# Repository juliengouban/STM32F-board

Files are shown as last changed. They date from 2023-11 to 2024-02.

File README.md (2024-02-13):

# Project PCB STM32F board



The PCB board is based on an STM32F microcontroller. It's similar to the ST Microelectronics Nucleo, which also features an STM32F. 

The board was realized on Altium Designer. It was produced by prototypist PCBway. This is a 4-layer PCB (top layer, GND layer, 3.3v layer and bottom layer) using vias.

*Project duration: 3 days*

# Table of contents
- [Electronic diagram](#electronic-diagram)
- [PCB Design](#pcb-design)

## Electronic diagram

The board's circuit diagram includes a two-pin male connector for the external power supply. This allows the board to be powered from 4 to 20 volts. A voltage regulator is used to convert the input voltage to 3.3V.

The middle of the page shows the STM32F microcontroller. It has 43 pins, 30 of which are GPIOS controllable. This board use an external quartz oscillator to provide a stable frequency for this board.
The Reset pin on the microcontroller is connected to a pushbutton to reset the STM32F board.The STM32F has different boot options. The user is given the choice with a male connector.
The STM32F board has a JTAG (Joint Test Action Group) interface for testing, debugging and programming this board.
The board has two female connectors for connecting components to the board's GPIO. There are 30 GPIOS usable on the STM32F board.

Each GPIO has a pull-up resistor.
The bypass capacitor (decoupling capacitor) is used on our board to stabilize the power supply to the components.

Its main role is to filter and eliminate the high-frequency electrical noise generated by these components.

For routing placement, the bypass capacitor is connected between the supply line and ground (GND) in the immediate vicinity of the component it supplies. 
Here is the complete circuit diagram:

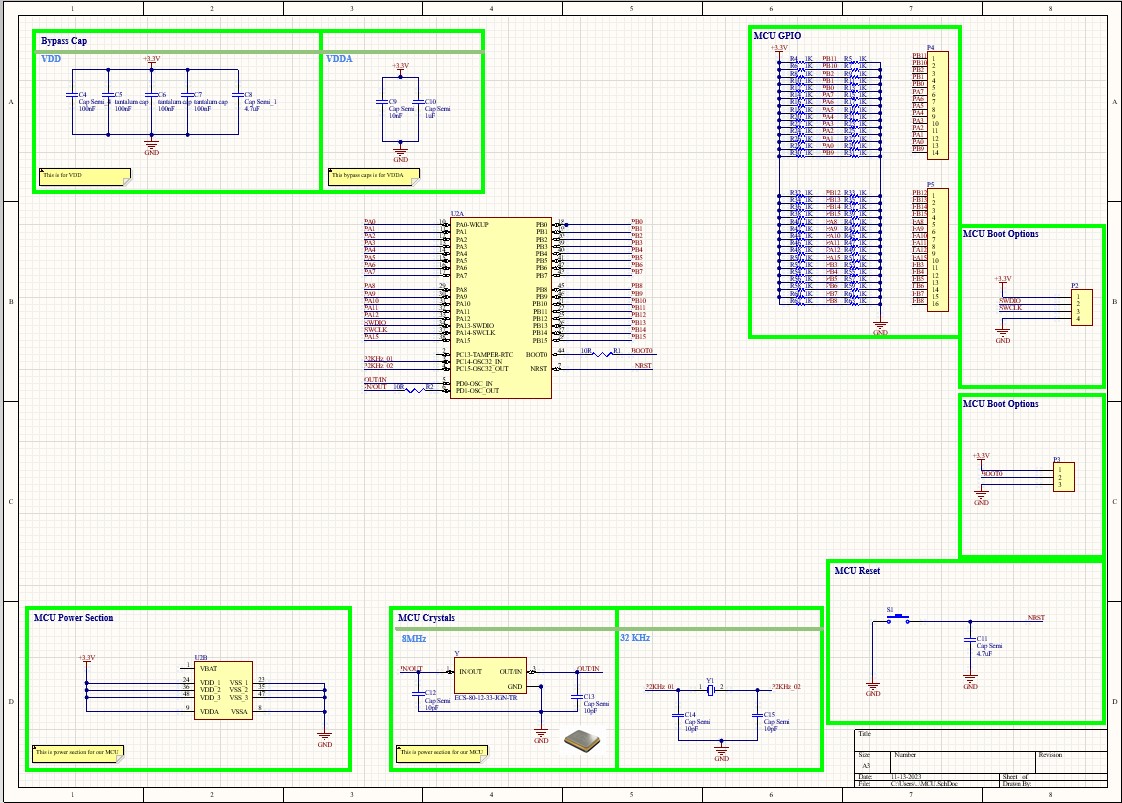
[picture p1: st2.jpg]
 

## PCB Design

The PCB has been realized on Altium Designer. It has a dimension of 6.5 cm and a height of 5 cm.  The board's top layer contains most of the components. 

Here's the top layer view of the PCB:

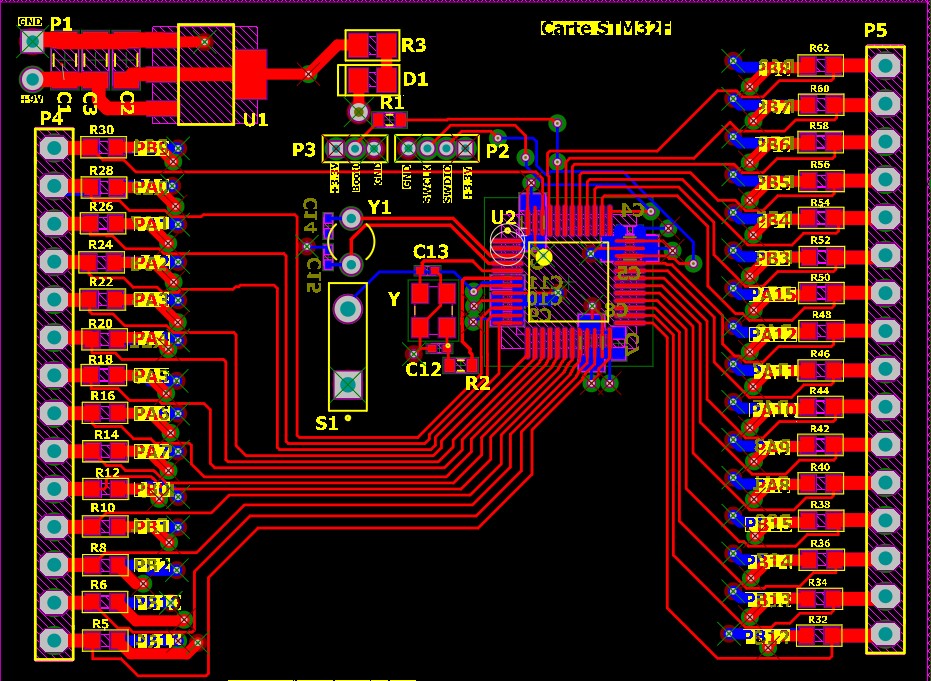
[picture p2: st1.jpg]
 

Here is a 3d view of the PCB:

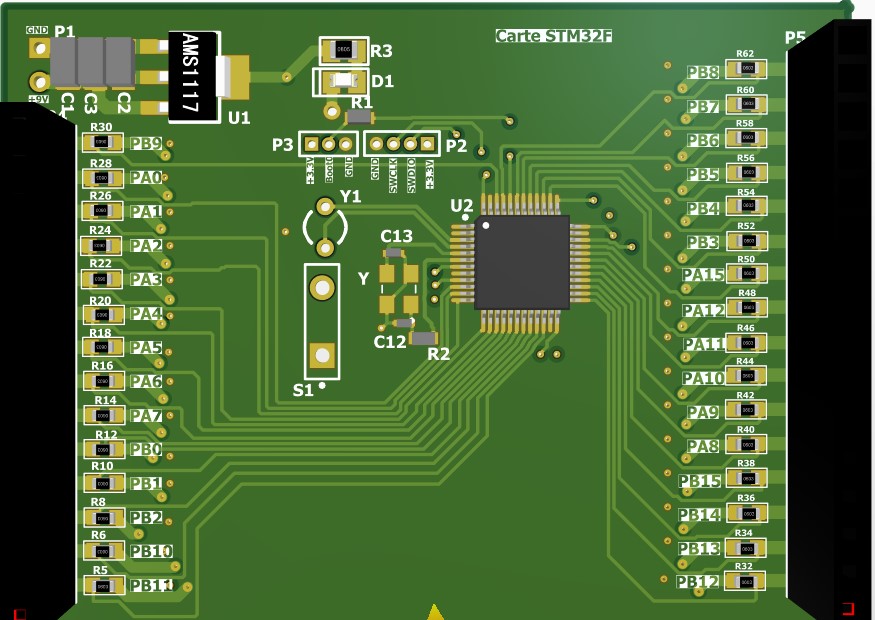
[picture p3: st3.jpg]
 

## Arduino Factory

 * [More details on this project](https://arduinofactory.fr/carte-pcb-stm32f/)

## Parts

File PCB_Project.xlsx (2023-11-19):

Comment | Description | Designator | Footprint | LibRef | Quantity
Cap Semi | Capacitor (Semiconductor SIM Model) | C1 | C1206 | Cap Semi | 1
Tantalum Cap | Capacitor (Semiconductor SIM Model) | C2, C3 | C1206 | Cap Semi | 2
Cap Semi_4 | Capacitor (Semiconductor SIM Model) | C4 | 0402cap | Cap Semi_4 | 1
tantalum cap | Capacitor (Semiconductor SIM Model) | C5, C6, C7 | C1206tancap | Cap Semi_5, Cap Semi_6 | 3
Cap Semi_1 | Capacitor (Semiconductor SIM Model) | C8 | 1608[0603]cap | Cap Semi_1_1 | 1
Cap Semi | Capacitor (Semiconductor SIM Model) | C9, C10, C11 | 1608[0603] | Cap Semi | 3
Cap Semi | Capacitor (Semiconductor SIM Model) | C12, C13, C14, C15 | 0402 | Cap Semi | 4
LED | Typical INFRARED GaAs LED | D1 | MY_LED_0805 | LED | 1
 | Header, 2-Pin, Right Angle | P1 | HDR1X2H | Header 2H | 1
 | Header, 4-Pin | P2 | MHDR1X4 | MHDR1X4 | 1
 | Header, 3-Pin | P3 | MHDR1X3 | MHDR1X3 | 1
Header 14 | Header, 14-Pin | P4 | MY_FE14 | Header 14 | 1
Header 16 | Header, 16-Pin | P5 | MY_FE16 | Header 16 | 1
Res3 | Resistor | R1, R2 | J1-0603 | Res3 | 2
330R | Standard resistor | R3 | MY_0805 | Res | 1
1K | Standard resistor | R4, R5, R6, R7, R8, R9, R10, R11, R12, R13, R14, R15, R16, R17, R18, R19, R20, R21, R22, R23, R24, R25, R26, R27, R28, R29, R30, R31, R32, R33, R34, R35, R36, R37, R38, R39, R40, R41, R42, R43, R44, R45, R46, R47, R48, R49, R50, R51, R52, R53, R54, R55, R56, R57, R58, R59, R60, R61, R62, R63 | MY_0603 | Res | 60
 | Switch | S1 | SPST-2 | SW-PB | 1
 | The LM1117 is a low dropout voltage regulator with a dropout of 1.2 V at 800 mA of load current. The LM1117 is available in an adjustable version, which can set the output voltage from 1.25 V to 13.8 V with only two external resistors. In addition, the device is available in five fixed voltages, 1.8 V, 2.5 V, 3.3 V, and 5 V. The LM1117 offers current limiting and thermal shutdown. The circuit includes a Zener trimmed band- gap reference to assure output voltage accuracy to within ±1%. A minimum of 10-μF tantalum capacitor is required at the output to improve the transient response and stability. | U1 | 4-pin SOT | LM1117 | 1
 | ARM Cortex-M3 32-bit MCU, 64 KB Flash, 20 KB Internal RAM, 37 I/Os, 48-pin LQFP, -40 to 85 degC, Tray | U2 | STM-LQFP48_M | STM32F103C8T6 | 1
ECS-80-12-33-JGN-TR | 8MHz Â±20ppm Crystal 12pF 400 Ohms 4-SMD, No Lead | Y | XTAL_ECS-240-8-33-AGN-TR | ECS-80-12-33-JGN-TR | 1
 | Crystal Oscillator | Y1 | R38 | XTAL | 1

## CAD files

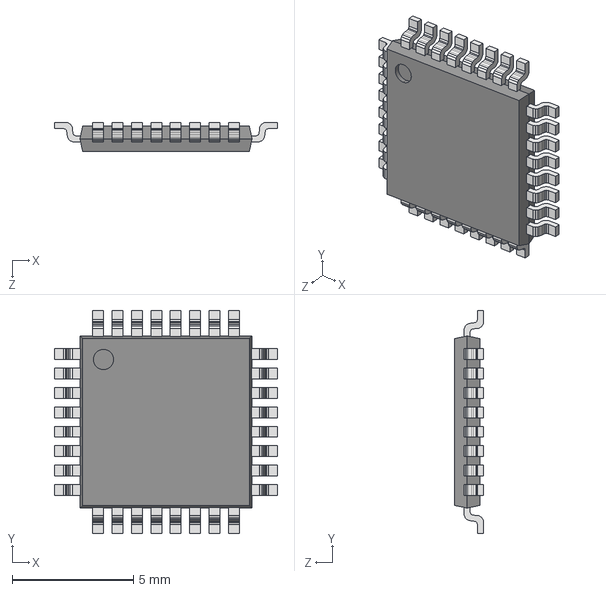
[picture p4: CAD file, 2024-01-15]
User Library-tqfp32.step
9.20 x 9.20 x 1.20 mm

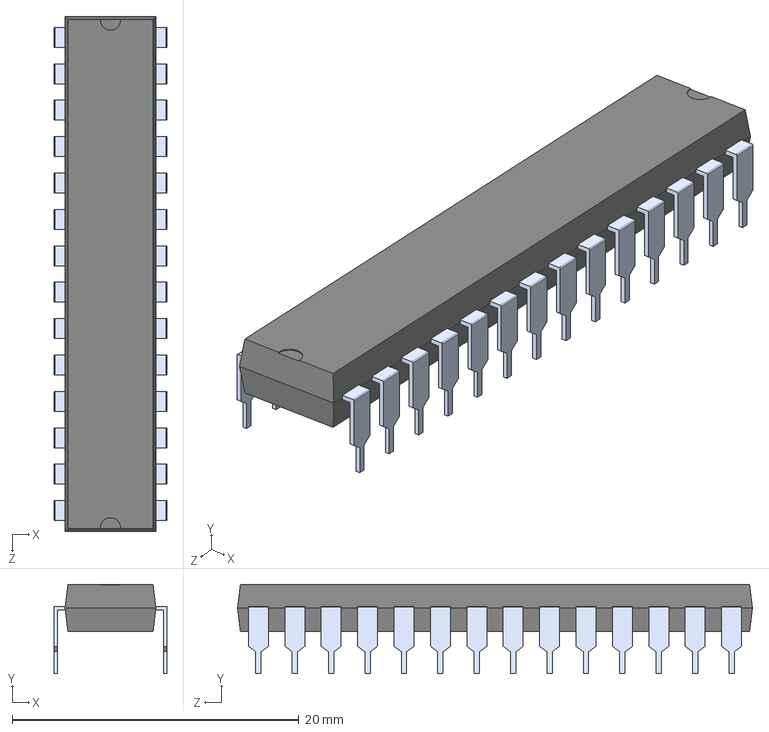
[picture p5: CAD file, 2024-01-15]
User Library-28 pin dip-1.STEP
7.87 x 6.22 x 35.9 mm
